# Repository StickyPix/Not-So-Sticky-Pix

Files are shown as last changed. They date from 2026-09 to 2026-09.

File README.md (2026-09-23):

# StickyPix

StickyPix is a small, rechargeable e-paper picture frame that lets you send
images from a phone or desktop app over Bluetooth Low Energy. The same product
family supports a four-gray black-and-white display and a six-color display.

## Image gallery

<table>
  <tr>
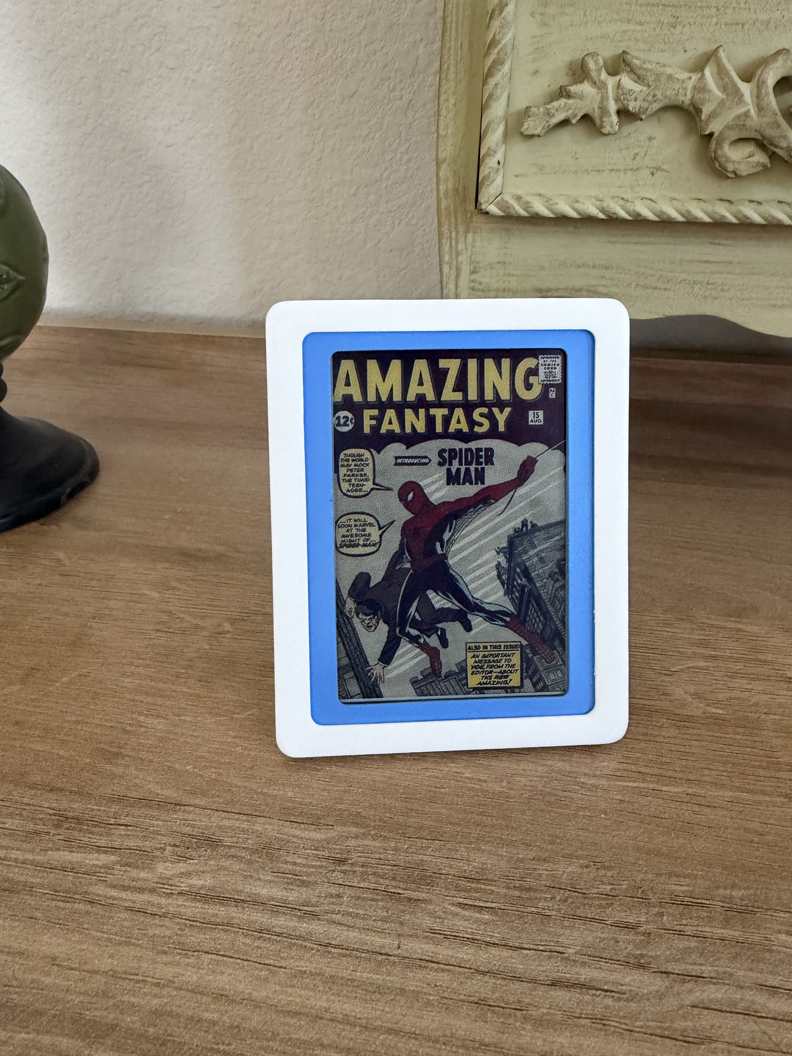
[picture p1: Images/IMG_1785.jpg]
StickyPix prototype photo 1
    <td></td>
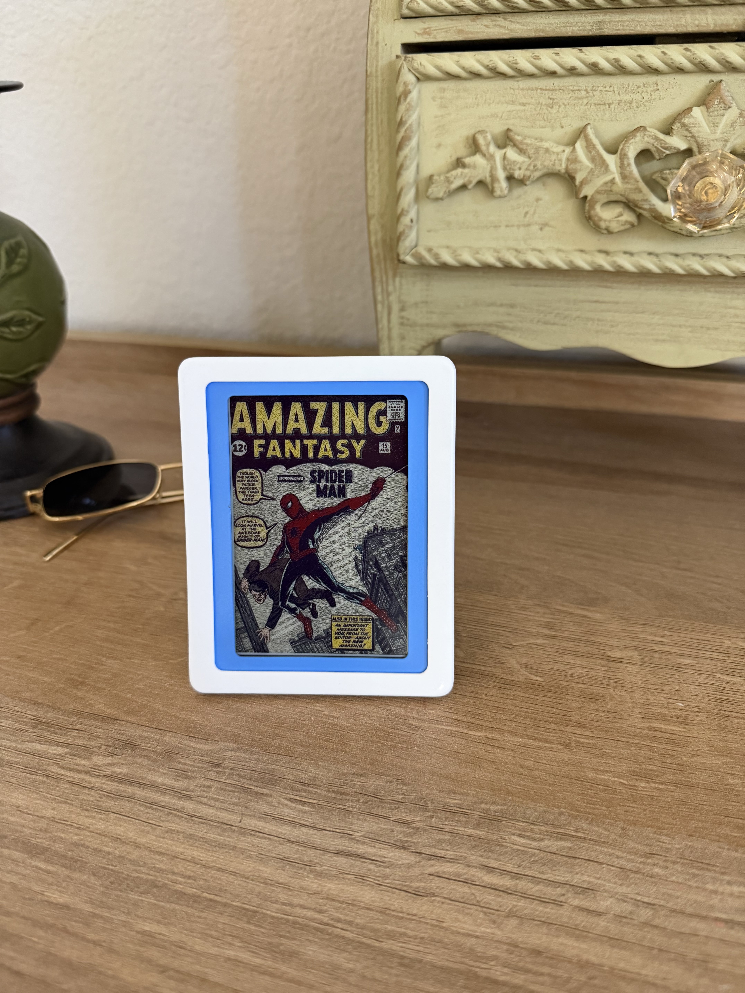
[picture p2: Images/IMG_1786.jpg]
StickyPix prototype photo 2
    <td></td>
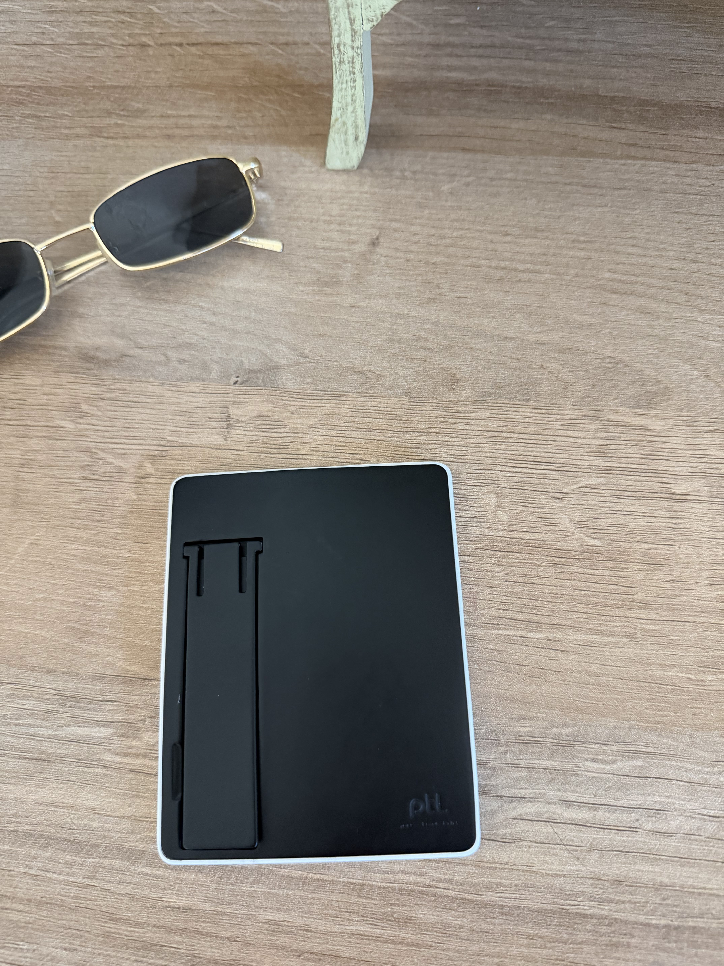
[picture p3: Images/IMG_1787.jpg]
StickyPix prototype photo 3
    <td></td>
  </tr>
  <tr>
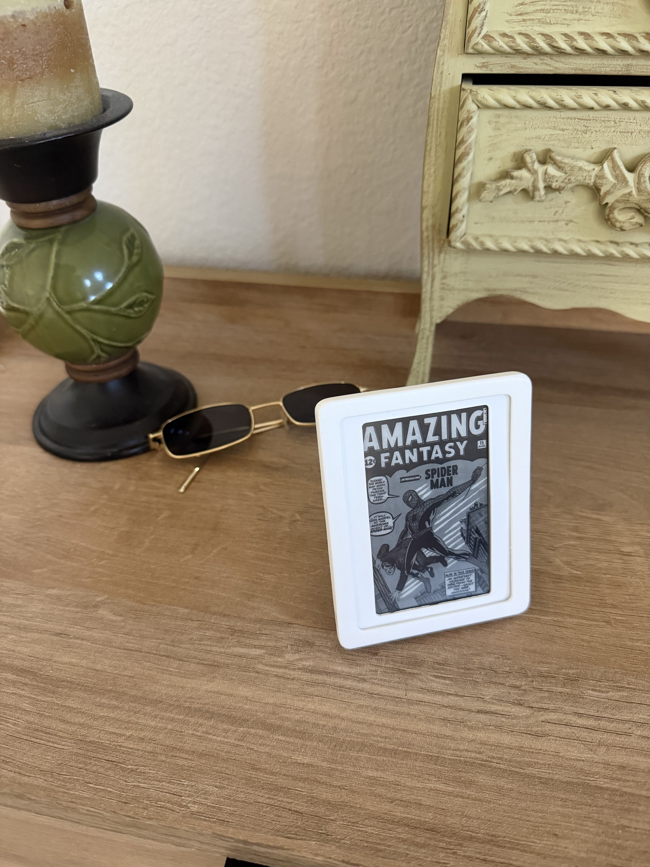
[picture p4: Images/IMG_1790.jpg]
StickyPix prototype photo 4
    <td></td>
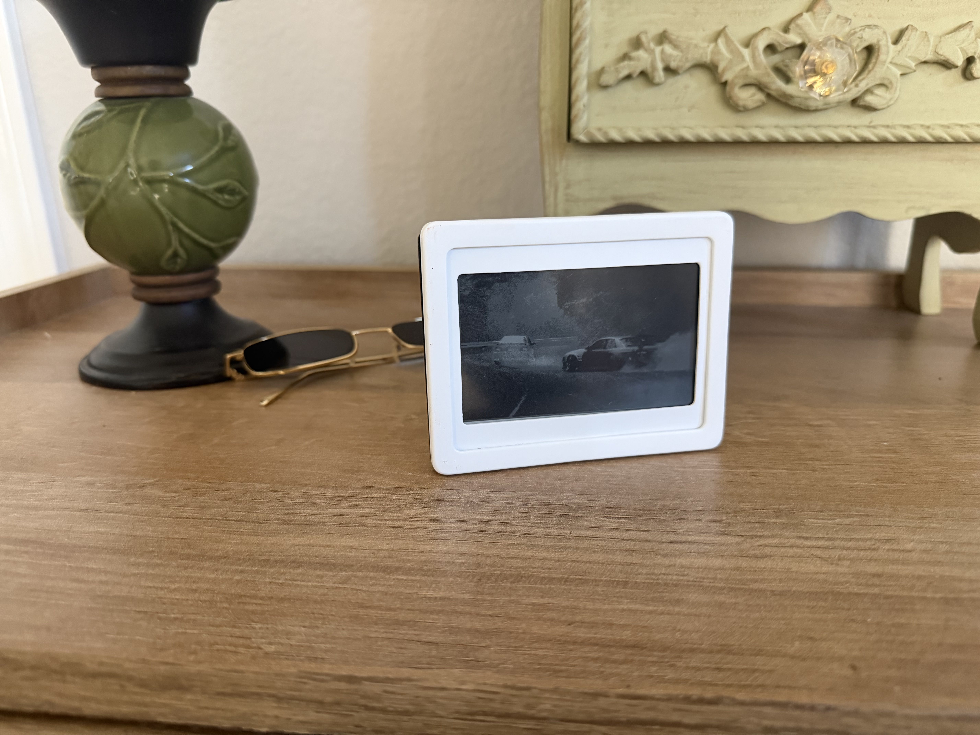
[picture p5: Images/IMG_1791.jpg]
StickyPix prototype photo 5
    <td></td>
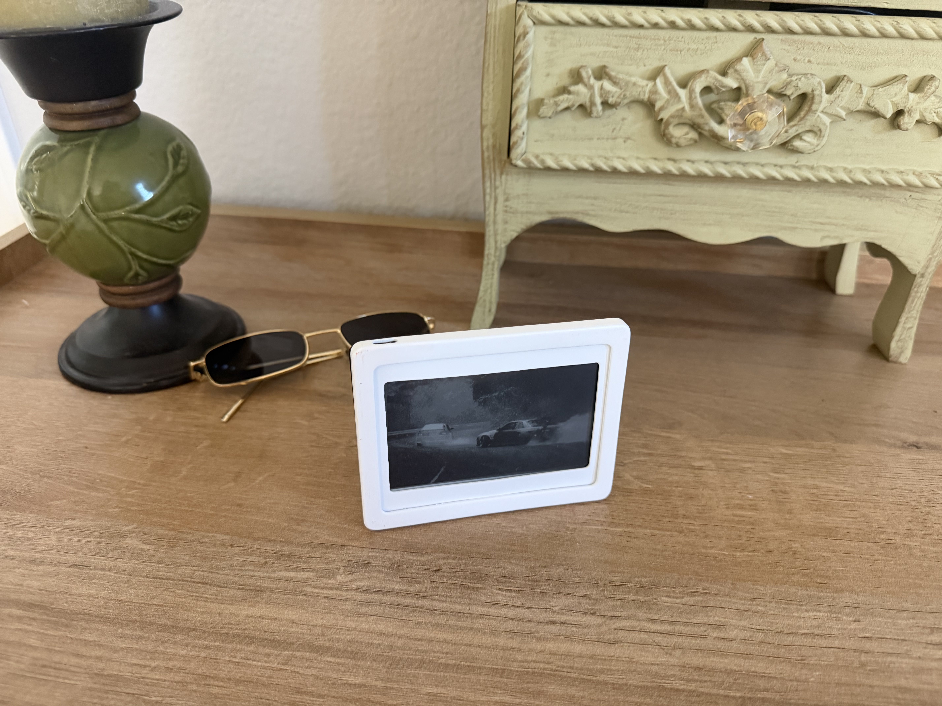
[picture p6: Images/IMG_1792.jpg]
StickyPix prototype photo 6
    <td></td>
  </tr>
  <tr>
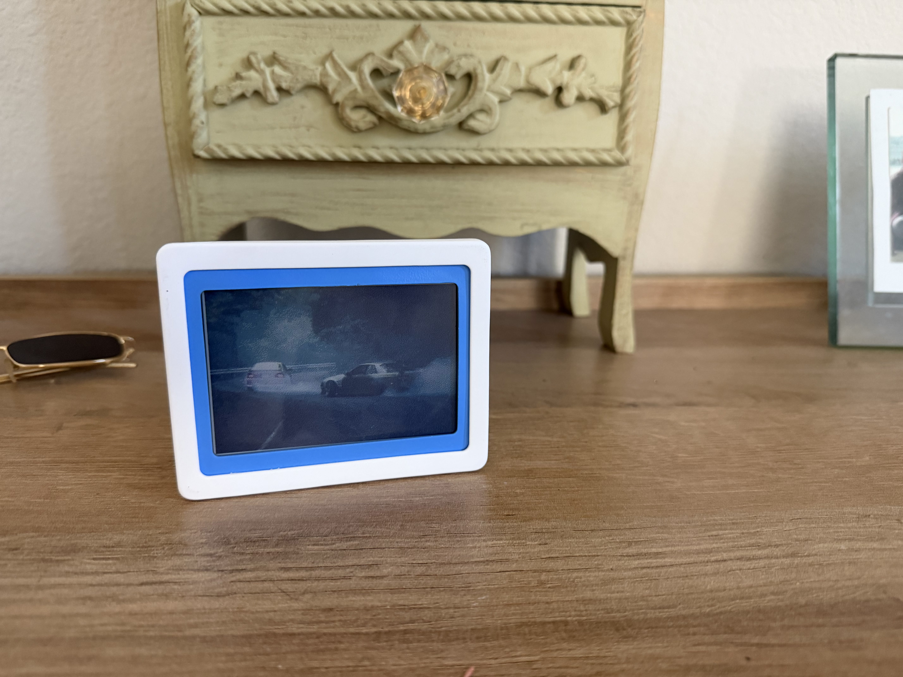
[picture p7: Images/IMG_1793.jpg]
StickyPix prototype photo 7
    <td></td>
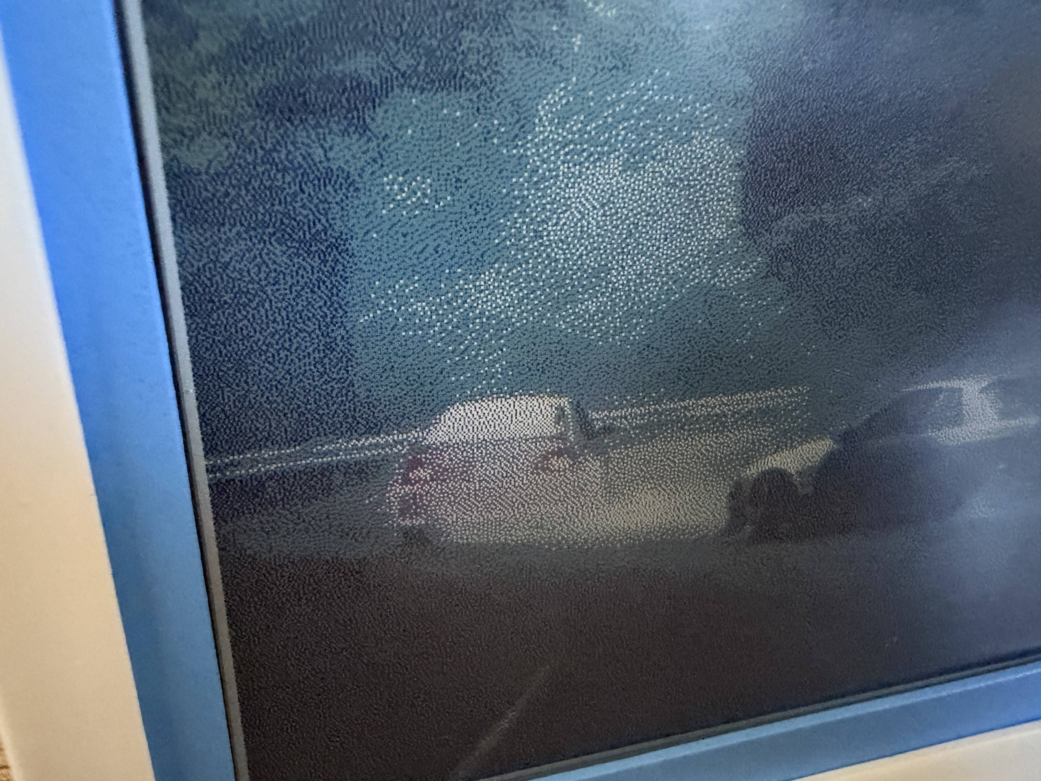
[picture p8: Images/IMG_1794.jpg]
StickyPix prototype photo 8
    <td></td>
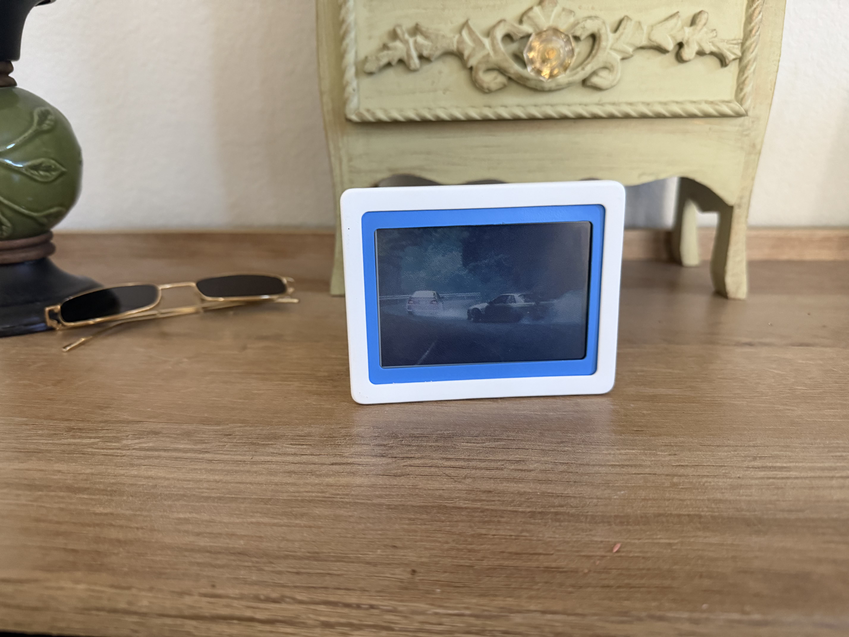
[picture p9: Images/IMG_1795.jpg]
StickyPix prototype photo 9
    <td></td>
  </tr>
</table>

## What is in this repository?

StickyPix is developed as a complete hardware and software product:

| Area | Contents |
| --- | --- |
| App | Flutter image editor, dithering previews, device management, and BLE image transfer |
| Firmware | Zephyr-based firmware for four-gray and six-color display variants |
| Hardware | KiCad schematics, PCBs, fabrication outputs, and bills of materials |
| Enclosure | Blender source files and printable STL parts for the bezel, rear shell, inner enclosure, and kickstand |
| Images | Prototype photos and product renders |

## How it works

1. Choose an image in the Flutter app.
2. Crop, rotate, and adjust the image for the selected device.
3. The app converts the image to the display's limited palette using dithering.
4. The processed framebuffer is sent to the device over BLE.
5. The device refreshes the e-paper panel and returns transfer progress and battery information.

The image pipeline currently supports:

- Four-gray output for the black-and-white display variant.
- Six-color output for black, white, yellow, red, blue, and green.
- Portrait and landscape editing for the six-color device.
- Packed framebuffer transfer sized for the target panel.

## Display variants

- [Six-color display / Spectra 6 panel](https://www.ebay.com/itm/267508191177?var=567305393025)
- [Black-and-white display panel](https://www.good-display.com/product/613.html)

The linked vendor pages are the reference parts for the current hardware
designs. Check the vendor documentation for the latest availability and
electrical specifications before ordering.

## JLCPCB fabrication settings

For the current PCB designs, I use the following JLCPCB configuration as the
fabrication reference:

| Setting | Value |
| --- | --- |
| Design | 1 |
| Delivery format | Single PCB |
| PCB thickness | 1.0 mm |
| PCB color | Green |
| Silkscreen | White |
| Material | FR4 TG135 |
| Surface finish | HASL (with lead) |
| Outer copper | 1 oz |
| Inner copper | 0.5 oz |
| Specify layer sequence | No |
| Specify stackup | Yes |
| Layer stackup | JLC04101H-3313 |

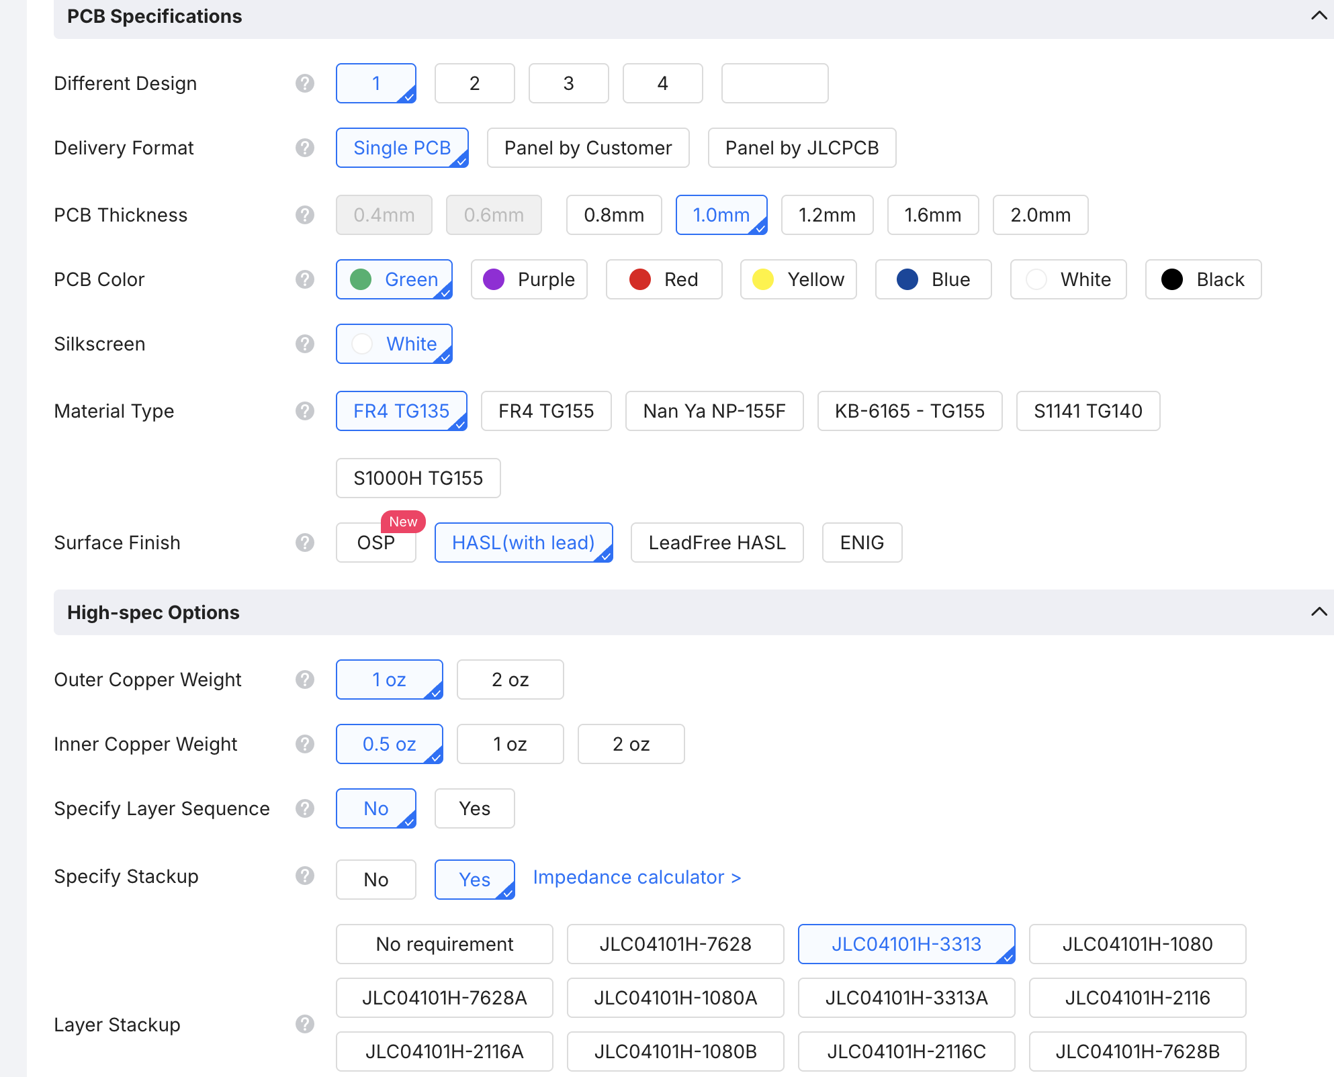
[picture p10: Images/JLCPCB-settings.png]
JLCPCB PCB specifications


Treat this as the current ordering reference, not a guarantee that every board
revision uses the same stackup. Recheck the board layer count, dimensions, and
JLCPCB options before placing an order.

## Enclosure

The enclosure is split into a front bezel, rear shell, inner cardstock/support
piece, and kickstand. The repository includes both the editable Blender model
and exported STL files.

<table>
  <tr>
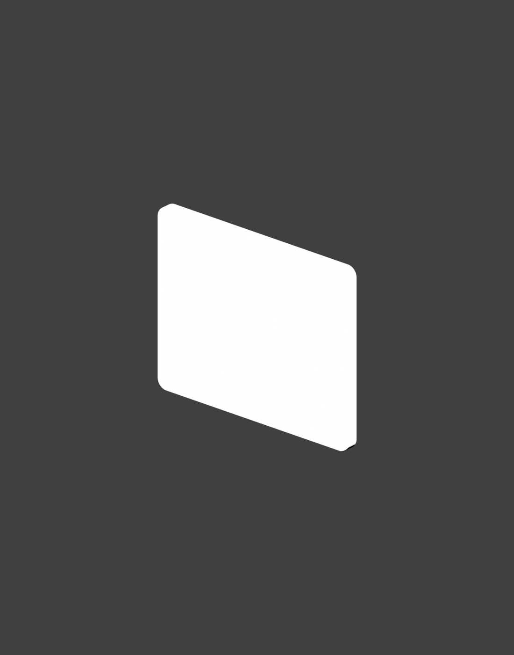
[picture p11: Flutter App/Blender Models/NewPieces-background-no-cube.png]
StickyPix enclosure render
    <td></td>
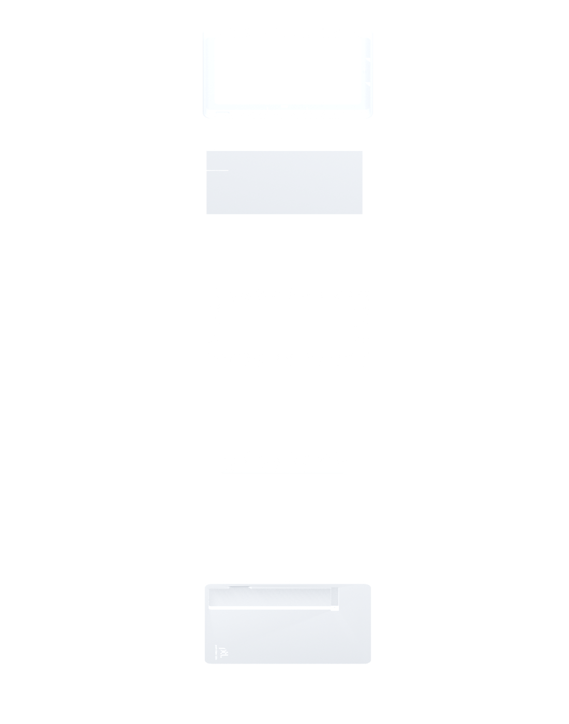
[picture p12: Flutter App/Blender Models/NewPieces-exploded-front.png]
StickyPix exploded enclosure render
    <td></td>
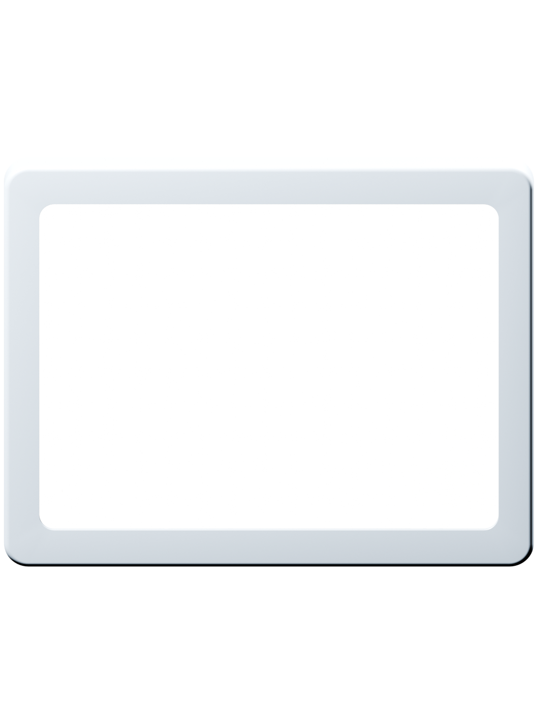
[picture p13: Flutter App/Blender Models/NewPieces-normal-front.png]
StickyPix enclosure front render
    <td></td>
  </tr>
</table>

## Repository layout

```text
Images/                         Prototype photos
3D Model/                       Printable enclosure STL files
Hardware/24p_bw_3p5/            Black-and-white KiCad design
Hardware/50p_spectra6_4/        Six-color KiCad design
Firmware/4GrayFinal/             Four-gray Zephyr firmware
Firmware/6ColorFinal/            Six-color Zephyr firmware
Flutter App/frontend/sticky_pix/ Flutter application
Manufacturing/                  Manufacturing files and BOM
```

## Project status

StickyPix is an active hardware prototype. The app, firmware, PCB designs, and
enclosure are included for development and iteration; dimensions, pinouts,
image timings, and manufacturing outputs may change.

## Development notes

The Flutter application is in `Flutter App/frontend/sticky_pix`. The firmware
projects use Zephyr and are kept separate so the four-gray and six-color panel
drivers can evolve independently. Build-tool-generated files and local SDK
paths should remain uncommitted.

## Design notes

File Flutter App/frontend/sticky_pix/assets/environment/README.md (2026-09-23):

# Studio image-based lighting

`default_env_ibl.ktx` is the Filament-compatible neutral environment bundled
with Thermion's own examples and tests:

https://github.com/nmfisher/thermion/blob/main/examples/assets/default_env_ibl.ktx

Only the indirect-light data is loaded. The environment is not displayed as a
skybox, so the Flutter background remains unchanged.

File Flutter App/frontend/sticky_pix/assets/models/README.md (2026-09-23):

# Product model contract

The viewer loads `device.glb` once and addresses model parts by glTF node name.
Keep these names stable in Blender:

- `4" Eink Display` — the complete display module in Blender. The preparation
  tool renames it `DisplayPlane` for reliable Thermion lookup and splits its
  recessed 84.6 × 56.4 mm active face into display primitive `2`.
- `Cube` — an export-only helper whose mesh is stripped from the packaged GLB.
  Thermion imports renderable nodes outside the active glTF scene, so scene
  exclusion alone is insufficient.
- `FrontShell (1.5Fillet) with clips (1)` — front bezel.
- `RearShell with Clips long` — rear enclosure.
- `Kickstand 1.5 (1) (1) (1)` — kickstand pivot object.
- `Cardstock 4` — inner enclosure.

The packaged model is generated from `Blender Models/NewPieces.glb` with
`tool/prepare_device_glb.dart`. It creates the dedicated `Display` primitive,
keeps the five named product pieces, excludes the unrelated `Cube`, applies the
safe mobile plastic material, and locks the product in portrait orientation.

Keep the display UV aspect ratio at 3:2 and orient UV0 so the upper-left of the
image appears at the upper-left of the physical display. Apply object scale and
rotation before export. Put the kickstand origin at its physical hinge and
export an animation named `KickstandOpen` when that animation is ready.

Recommended Blender materials:

- Front shell, cardstock, and kickstand PC/ABS: `#F5F5F5`.
- Rear shell PC/ABS: baby blue `#89CFF0`.
- All PC/ABS: metallic `0`, roughness `0.12` for a high-gloss finish.
  Thermion 0.4.1's default
  mobile ubershader cannot safely load the glTF clearcoat/IOR combination, so
  the glossy injection-molded finish is represented by low roughness instead.
- The export-only `Cube` is excluded because it is not one of the five named
  NewPieces product components.
- Display: matte black placeholder, with UV0 retained in the GLB.

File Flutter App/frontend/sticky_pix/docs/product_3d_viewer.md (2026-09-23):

# Reusable 3D product viewer

`Product3dViewer` is the Flutter presentation layer. It owns one Thermion
viewer, one loaded glTF asset, the camera input delegate, and GPU resources.
`ProductViewerController` is the application-facing API. The image processor
never talks directly to Filament.

## Runtime flow

1. The bundled 1.5 MB GLB is loaded once and normalized to a unit cube.
2. Named glTF entities receive independent Filament PBR material instances.
3. Primitive `2` of runtime entity `DisplayPlane` (the Blender node named
   `4" Eink Display`) receives an unlit texture material using UV0. The display
   module body and connector retain their own materials.
4. Processed PNG bytes are decoded and uploaded as a GPU texture.
5. The new texture replaces the old texture on the material; the model and UV
   mapping remain loaded and unchanged.
6. Edit and Save animate the existing camera between configurable poses.

## Public control surface

```dart
final controller = ProductViewerController();

Product3dViewer(controller: controller);

await controller.setDisplayTexture(processedPng);
await controller.focusDisplay();
await controller.showOverview();
await controller.setPartColor(ProductPart.kickstand, const Color(0xFF222222));
```

Each device model supplies a `ProductModelConfig`, so new hardware variants do
not require changes to rendering code. Put their node names, asset path, camera
poses, and optional IBL/skybox paths in a new config.

## Performance budget

- The render loop is capped at 60 FPS.
- The GLB is loaded once; image changes do not reload it.
- Display textures use mipmaps to avoid shimmer when the device rotates.
- GPU textures and custom material instances are explicitly released.
- The viewport is isolated behind a `RepaintBoundary`.
- Keep mobile GLBs below roughly 100k triangles, use one UV set for the
  display, prefer 1K–2K textures, and use KTX2/Basis textures for larger
  production assets.

## Blender/export contract

See `assets/models/README.md`. In particular, keep the part node names stable,
keep the `4" Eink Display` active surface dimensions unchanged, and position
the kickstand origin at its hinge. Export a `KickstandOpen` glTF animation
before adding the controller action for it.

For a more reflective studio look, add mobile-sized Filament IBL and skybox KTX
assets and set `iblPath`/`skyboxPath` on the model config. Direct three-point
lighting is the current fallback.

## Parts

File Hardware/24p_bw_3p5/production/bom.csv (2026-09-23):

Designator | Footprint | Quantity | Value | LCSC Part #
AE2 | 2.4GHz_Left_PC_ABS | 1 | Antenna_Shield
C1 | 0201 | 1 | 1.5pF
C10, C12, C14, C15, C44, C5, C7 | 0603 | 7 | 4.7uF
C16, C18 | 0402 | 2 | 1uF
C17 | 0201 | 1 | 3.9pF
C19, C28 | 0201 | 2 | 2.2uF
C2 | 0201 | 1 | 2pF
C20, C21, C22, C25 | 0201 | 4 | 100nF
C23 | 0201 | 1 | 2.2nF
C24 | 0402 | 1 | 0.1uF
C26, C29, C30 | 0402 | 3 | 10uF
C27 | 0201 | 1 | 10nF
C3, C6, C9 | 0603 | 3 | 1uF
C8 | 0201 | 1 | 0.3pF
D1, D2, D3 | D_SOD-323 | 3 | 1N5819WS
FB1 | 0201 | 1 | FerriteBead
J1 | HRS_FH34SRJ-24S-0.5SH_50_ | 1 | FH34SRJ-24S-0.5SH_50_
J2 | USB_C_SHOU_HAN_6P | 1 | USB_C_Receptacle_PowerOnly_6P
J3 | BATTERY_HC-1.2-2PWT | 1 | BATTERY
J4 | PinHeader_1x04_P2.54mm_Vertical | 1 | Conn_01x04_Pin
J5, J6 | PinHeader_1x03_P2.54mm_Vertical | 2 | Conn_01x03_Pin
L1 | 0201 | 1 | 2.7nH
L2, L3 | 0201 | 2 | 3.5nH
L4 | L_Cenker_CKCS3012 | 1 | 47uH
L5 | 0603 | 1 | 4.7uH
Q1 | SOT-323_SC-70 | 1 | Si1308EDL
R1 | 0402 | 1 | 2.2
R10, R7 | 0402 | 2 | 10k
R2, R4 | 0402 | 2 | 5.1k
R3 | 0402 | 1 | 1M
R5 | 0201 | 1 | 1k
R6 | 0402 | 1 | 5.4k
R8 | 0402 | 1 | 2k
R9 | 0402 | 1 | 100
U1 | DFN1006-2 | 1 | ESD5451N
U2 | IC_BQ24045DSQR | 1 | BQ24040DSQR
U3 | QFN40P600X600X90-49N | 1 | NRF54L15-QFAA-R
U4 | UDFN-4-1EP_1x1mm_P0.65mm_EP0.48x0.48mm | 1 | FH8614G1
U6 | SOT-23-3 | 1 | GR6206P332MR-G
Y2 | Crystal_SMD_2016-4Pin_2.0x1.6mm | 1 | Crystal_GND24

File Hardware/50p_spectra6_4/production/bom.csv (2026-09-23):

Designator | Footprint | Quantity | Value | LCSC Part #
AE1 | 2.4GHz_Left_Soldermask | 1 | Antenna_Shield
C1 | 0201 | 1 | 1.5pF
C10, C11, C37, C38, C39, C41, C5, C6, C7, C9 | 0603 | 10 | 10uF
C12 | 0402 | 1 | 470nF
C13 | 0402 | 1 | 100nF
C14, C31 | 0402 | 2 | 2.2uF
C15, C16, C18, C32, C33, C34, C35 | 0402 | 7 | 1uF
C17 | 0201 | 1 | 3.9pF
C19, C28 | 0201 | 2 | 2.2uF
C2 | 0201 | 1 | 2pF
C20, C21, C22, C25 | 0201 | 4 | 100nF
C23 | 0201 | 1 | 2.2nF
C24 | 0402 | 1 | 0.1uF
C26, C29, C30 | 0402 | 3 | 10uF
C27 | 0201 | 1 | 10nF
C3, C36, C40 | 0402 | 3 | 4.7uF
C4 | 0402 | 1 | 0.47uF
C8 | 0201 | 1 | 0.3pF
D1, D2, D3, D4 | D_SOD-123 | 4 | MBR0530
FB1 | 0201 | 1 | FerriteBead
J1, J5 | PinHeader_1x03_P2.54mm_Vertical | 2 | Conn_01x03_Pin
J2 | USB_C_SHOU_HAN_6P | 1 | USB_C_Receptacle_PowerOnly_6P
J3 | BATTERY_HC-1.2-2PWT | 1 | BATTERY
J4 | PinHeader_1x04_P2.54mm_Vertical | 1 | Conn_01x04_Pin
J6 | PinHeader_1x02_P2.54mm_Vertical | 1 | Conn_01x02_Pin
J7 | HRS_FH34SRJ-50S-0.5SH_50_ | 1 | FH34SRJ-50S-0.5SH_50_
L1 | 0201 | 1 | 2.7nH
L2, L3 | 0201 | 2 | 3.5nH
L4, L6 | L_Changjiang_FNR4012S | 2 | 10uH
L5 | 0603 | 1 | 4.7uH
Q1 | SOT95P237X111-3N | 1 | BSS138LT1G
Q2 | SOT-23 | 1 | SI2301CDS-T1-GE3
R1, R15 | 0402 | 2 | 1M
R10, R11, R2, R4 | 0402 | 4 | 5.1k
R12, R17, R18, R7 | 0402 | 4 | 10k
R13 | 0402 | 1 | 0.01
R14 | 0402 | 1 | 0
R16, R3 | 0402 | 2 | 0.2
R5 | 0201 | 1 | 1k
R6 | 0402 | 1 | 5.4k
R8 | 0402 | 1 | 2k
R9 | 0402 | 1 | 100
U1 | DFN1006-2 | 1 | ESD5451N
U2 | IC_BQ24045DSQR | 1 | BQ24040DSQR
U3 | QFN40P600X600X90-49N | 1 | NRF54L15-QFAA-R
U4 | UDFN-4-1EP_1x1mm_P0.65mm_EP0.48x0.48mm | 1 | FH8614G1
U5 | BGA9C50P3X3_158X162X62 | 1 | BQ27220YZFR
U6 | SOT-23-3 | 1 | GR6206P332MR-G
U7 | ZD25WQ80CEIGR | 1 | ZD25WQ80C
Y2 | Crystal_SMD_2016-4Pin_2.0x1.6mm | 1 | Crystal_GND24

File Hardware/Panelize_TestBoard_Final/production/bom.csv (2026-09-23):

Designator | Footprint | Quantity | Value | LCSC Part #
AE1 | 2.4GHz_Left_Soldermask | 1 | Antenna_Shield
AE2 | 2.4GHz_Left_PC_ABS | 1 | Antenna_Shield
C1_2, C1 | 0201 | 2 | 1.5pF
C10_2, C12_2, C14_2, C15_2, C44, C5_2, C7_2 | 0603 | 7 | 4.7uF
C10, C11, C37, C38, C39, C41, C5, C6, C7, C9 | 0603 | 10 | 10uF
C12 | 0402 | 1 | 470nF
C13 | 0402 | 1 | 100nF
C14, C31 | 0402 | 2 | 2.2uF
C15, C16_2, C16, C18_2, C18, C32, C33, C34, C35 | 0402 | 9 | 1uF
C17_2, C17 | 0201 | 2 | 3.9pF
C19_2, C19, C28_2, C28 | 0201 | 4 | 2.2uF
C2_2, C2 | 0201 | 2 | 2pF
C20_2, C20, C21_2, C21, C22_2, C22, C25_2, C25 | 0201 | 8 | 100nF
C23_2, C23 | 0201 | 2 | 2.2nF
C24_2, C24 | 0402 | 2 | 0.1uF
C26_2, C26, C29_2, C29, C30_2, C30 | 0402 | 6 | 10uF
C27_2, C27 | 0201 | 2 | 10nF
C3_2, C6_2, C9_2 | 0603 | 3 | 1uF
C3, C36, C40 | 0402 | 3 | 4.7uF
C4 | 0402 | 1 | 0.47uF
C8_2, C8 | 0201 | 2 | 0.3pF
D1_2, D2_2, D3_2 | D_SOD-323 | 3 | 1N5819WS
D1, D2, D3, D4 | D_SOD-123 | 4 | MBR0530
FB1_2, FB1 | 0201 | 2 | FerriteBead
J1_2 | HRS_FH34SRJ-24S-0.5SH_50_ | 1 | FH34SRJ-24S-0.5SH_50_
J1, J5_2, J5, J6_2 | PinHeader_1x03_P2.54mm_Vertical | 4 | Conn_01x03_Pin
J2_2, J2 | USB_C_SHOU_HAN_6P | 2 | USB_C_Receptacle_PowerOnly_6P
J3_2, J3 | BATTERY_HC-1.2-2PWT | 2 | BATTERY
J4_2, J4 | PinHeader_1x04_P2.54mm_Vertical | 2 | Conn_01x04_Pin
J6 | PinHeader_1x02_P2.54mm_Vertical | 1 | Conn_01x02_Pin
J7 | HRS_FH34SRJ-50S-0.5SH_50_ | 1 | FH34SRJ-50S-0.5SH_50_
L1_2, L1 | 0201 | 2 | 2.7nH
L2_2, L2, L3_2, L3 | 0201 | 4 | 3.5nH
L4_2 | L_Cenker_CKCS3012 | 1 | 47uH
L4, L6 | L_Changjiang_FNR4012S | 2 | 10uH
L5_2, L5 | 0603 | 2 | 4.7uH
MOUSE-BITE-3MM-SLOT_3, MOUSE-BITE-3MM-SLOT_2, MOUSE-BITE-3MM-SLOT | mouse-bite-3mm-slot | 3 | VAL**
Q1_2 | SOT-323_SC-70 | 1 | Si1308EDL
Q1 | SOT95P237X111-3N | 1 | BSS138LT1G
Q2 | SOT-23 | 1 | SI2301CDS-T1-GE3
R1_2 | 0402 | 1 | 2.2
R1, R15, R3_2 | 0402 | 3 | 1M
R10_2, R12, R17, R18, R7_2, R7 | 0402 | 6 | 10k
R10, R11, R2_2, R2, R4_2, R4 | 0402 | 6 | 5.1k
R13 | 0402 | 1 | 0.01
R14 | 0402 | 1 | 0
R16, R3 | 0402 | 2 | 0.2
R5_2, R5 | 0201 | 2 | 1k
R6_2, R6 | 0402 | 2 | 5.4k
R8_2, R8 | 0402 | 2 | 2k
R9_2, R9 | 0402 | 2 | 100
U1_2, U1 | DFN1006-2 | 2 | ESD5451N
U2_2, U2 | IC_BQ24045DSQR | 2 | BQ24040DSQR
U3_2, U3 | QFN40P600X600X90-49N | 2 | NRF54L15-QFAA-R
U4_2, U4 | UDFN-4-1EP_1x1mm_P0.65mm_EP0.48x0.48mm | 2 | FH8614G1
U5 | BGA9C50P3X3_158X162X62 | 1 | BQ27220YZFR
U6_2, U6 | SOT-23-3 | 2 | GR6206P332MR-G
Y2_2, Y2 | Crystal_SMD_2016-4Pin_2.0x1.6mm | 2 | Crystal_GND24

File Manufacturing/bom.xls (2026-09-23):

Comment | Designator | Footprint | JLCPCB Part # | Qty | Ext.Price($)
NRF54L15-QFAA-R | U3_2,U3 | QFN40P600X600X90-49N | C42458750 | 4 | 0.00
2.2nF | C23_2,C23 | 0201 | C80433 | 20 | 0.03
1k | R5_2,R5 | 0201 | C100125 | 20 | 0.02
4.7uH | L5_2,L5 | 0603 | C1034 | 20 | 0.44
MBR0530 | D1,D2,D3,D4 | D_SOD-123 | C77336 | 12 | 0.44
10uF | C10,C11,C37,C38,C39,C41,C5,C6,C7,C9 | 0603 | C96446 | 28 | 1.48
10k | R10_2,R12,R17,R18,R7_2,R7 | 0402 | C25744 | 22 | 0.06
4.7uF | C3,C36,C40 | 0402 | C2858031 | 10 | 0.70
ESD5451N | U1_2,U1 | DFN1006-2 | C5261080 | 20 | 0.15
0.1uF | C13,C24_2,C24 | 0402 | C307331 | 20 | 0.15
4.7uF | C10_2,C12_2,C14_2,C15_2,C44,C5_2,C7_2 | 0603 | C69335 | 22 | 1.07
2.2uF | C19_2,C19,C28_2,C28 | 0201 | C318539 | 20 | 0.44
100nF | C20_2,C20,C21_2,C21,C22_2,C22,C25_2,C25 | 0201 | C76934 | 28 | 0.06
3.5nH | L2_2,L2,L3_2,L3 | 0201 | C3911055 | 12 | 0.78
1.5pF | C1_2,C1 | 0201 | C435397 | 20 | 0.72
1N5819WS | D1_2,D2_2,D3_2 | D_SOD-323 | C191023 | 20 | 0.22
2pF | C2_2,C2 | 0201 | C668326 | 20 | 0.50
2.2uF | C14,C31 | 0402 | C72203 | 8 | 0.38
5.1k | R10,R11,R2_2,R2,R4_2,R4 | 0402 | C25905 | 22 | 0.02
2k | R8_2,R8 | 0402 | C4109 | 20 | 0.02
1M | R1,R15,R3_2 | 0402 | C26083 | 20 | 0.02
GR6206P332MR-G | U6_2,U6 | SOT-23-3 | C19631737 | 10 | 0.14
FerriteBead | FB1_2,FB1 | 0201 | C83991 | 20 | 0.29
1uF | C3_2,C6_2,C9_2 | 0603 | C15849 | 20 | 0.59
BQ24040DSQR | U2_2,U2 | IC_BQ24045DSQR | C81080 | 5 | 1.89
10uH | L4,L6 | L_Changjiang_FNR4012S | C525662 | 6 | 0.79
0.01 | R13 | 0402 | C2089431 | 5 | 0.64
Si1308EDL | Q1_2 | SOT-323_SC-70 | C7603347 | 6 | 0.54
10nF | C27_2,C27 | 0201 | C285010 | 20 | 0.04
100 | R9_2,R9 | 0402 | C25076 | 20 | 0.02
FH34SRJ-24S-0.5SH_50_ | J1_2 | HRS_FH34SRJ-24S-0.5SH_50_ | C324726 | 2 | 0.57
0.3pF | C8_2,C8 | 0201 | C301897 | 20 | 0.02
FH8614G1 | U4_2,U4 | UDFN-4-1EP_1x1mm_P0.65mm_EP0.48x0.48mm | C2929074 | 6 | 0.17
5.4k | R6_2,R6 | 0402 | C5948099 | 20 | 0.68
FH34SRJ-50S-0.5SH_50_ | J7 | HRS_FH34SRJ-50S-0.5SH_50_ | C3169104 | 2 | 1.16
10uF | C26_2,C26,C29_2,C29,C30_2,C30 | 0402 | C15525 | 22 | 0.43
0.2 | R16,R3 | 0402 | C270629 | 20 | 0.12
1uF | C15,C16_2,C16,C18_2,C18,C32,C33,C34,C35 | 0402 | C52923 | 28 | 0.39
BQ27220YZFR | U5 | BGA9C50P3X3_158X162X62 | C528617 | 2 | 1.30
2.7nH | L1_2,L1 | 0201 | C7216765 | 8 | 0.28
BATTERY | J3_2,J3 | BATTERY_HC-1.2-2PWT | C2997425 | 6 | 0.89
3.9pF | C17_2,C17 | 0201 | C76926 | 20 | 0.04
0 | R14 | 0402 | C17168 | 20 | 0.02
0.47uF | C4,C12 | 0402 | C2443204 | 20 | 0.30
BSS138LT1G | Q1 | SOT95P237X111-3N | C82045 | 6 | 0.25
Crystal_GND24 | Y2_2,Y2 | Crystal_SMD_2016-4Pin_2.0x1.6mm | C718072 | 6 | 0.65
USB_C_Receptacle_PowerOnly_6P | J2_2,J2 | USB_C_SHOU_HAN_6P | C2858273 | 4 | 0.29
47uH | L4_2 | L_Cenker_CKCS3012 | C5289292 | 6 | 0.27
2.2 | R1_2 | 0402 | C325532 | 20 | 0.07
SI2301CDS-T1-GE3 | Q2 | SOT-23 | C10487 | 6 | 0.43

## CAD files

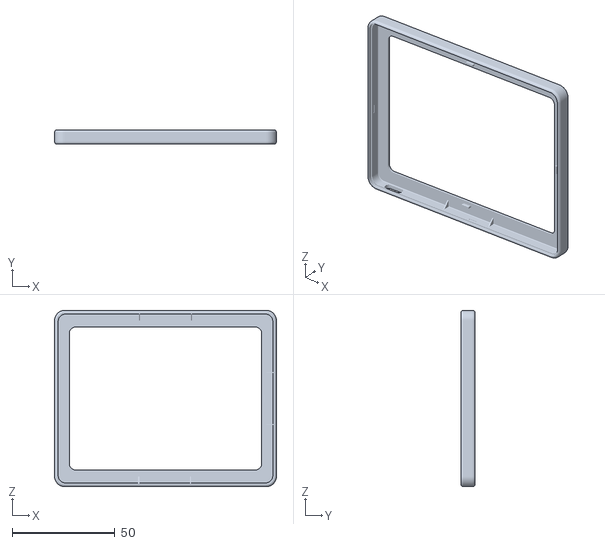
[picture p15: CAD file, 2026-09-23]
3D Model/FrontShell (1.5Fillet) with clips (1).stl
108.0 x 6.95 x 85.8

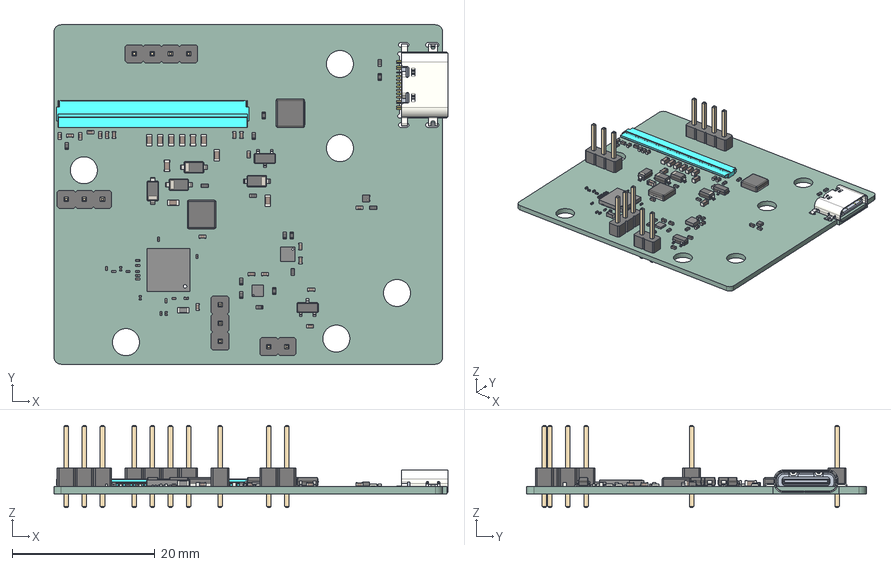
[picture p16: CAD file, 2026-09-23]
Hardware/50p_spectra6_4/50p_spectra6_4.step
55.2 x 47.6 x 11.5 mm
R_0402_1005Metric x 15
C_0201_0603Metric x 13
D_SOD_123 x 4
L_0603_1608Metric
C_0402_1005Metric x 19
C_0603_1608Metric x 10
L_Changjiang_FNR4012S x 2
NRF54L15-QFAA-R
DFN_4_1EP_1x1mm_P065mm_EP05x05mm
L_0201_0603Metric x 3
6_50_83D0001
PinHeader_1x03_P254mm_Vertical x 2
FH34SRJ-50S-0.5SH
DSQ10
PinHeader_1x02_P254mm_Vertical
SOT_23
R_0201_0603Metric
BQ27427YZFR
SOT-23-3
PinHeader_1x04_P254mm_Vertical
50p_spectra6_4_PCB_1
50p_spectra6_4_PCB_2

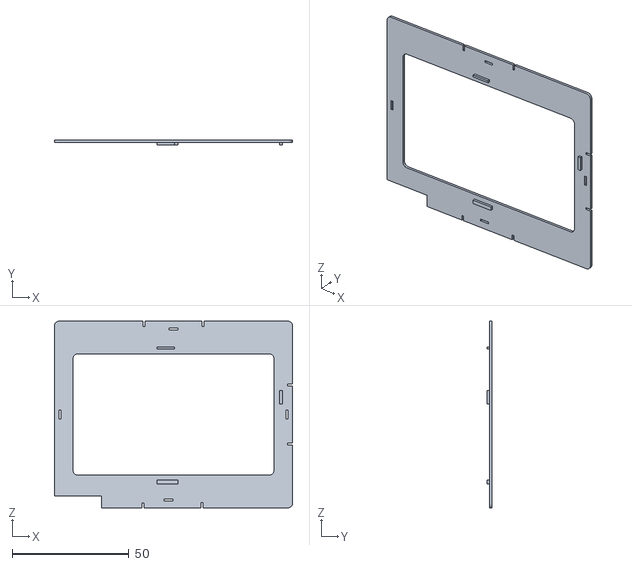
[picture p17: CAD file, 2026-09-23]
3D Model/Cardstock 3.97.stl
102.0 x 2.00 x 80.0

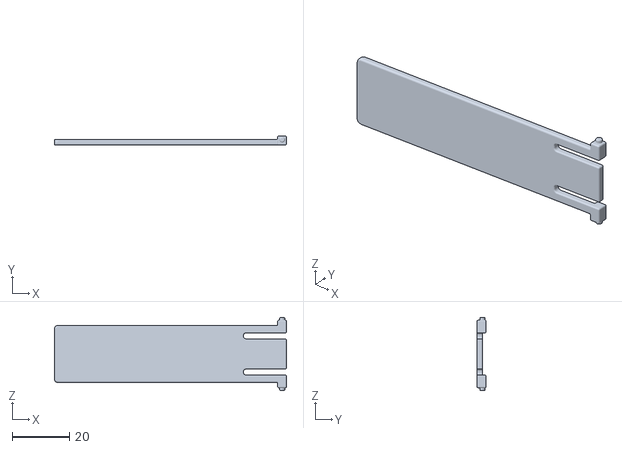
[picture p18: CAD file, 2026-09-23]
3D Model/Kickstand 1.5 newest.stl
81.0 x 3.20 x 25.6

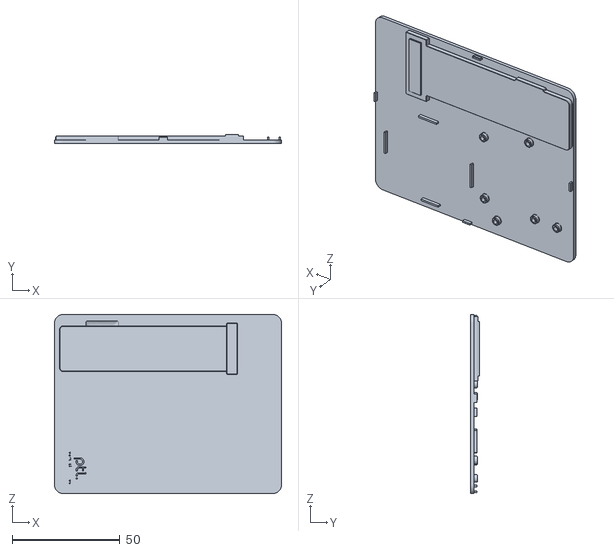
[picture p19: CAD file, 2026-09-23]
3D Model/RearShell with Clips long.stl
105.5 x 4.10 x 83.2

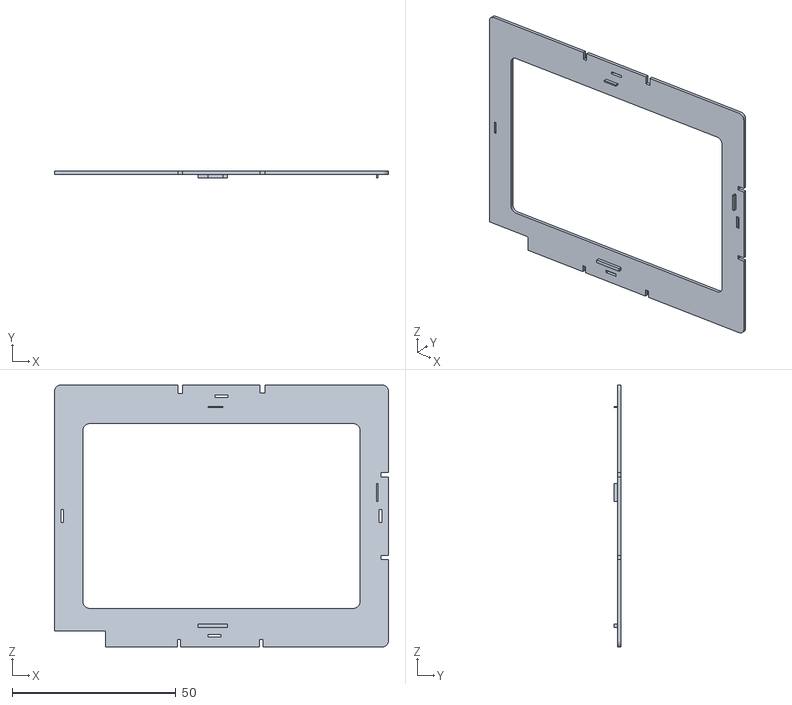
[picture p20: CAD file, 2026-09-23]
3D Model/Cardstock 4.stl
102.0 x 2.00 x 80.0

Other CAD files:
3D Model/Spectra6_4in.f3z
Flutter App/Blender Models/3DMODEL4IN.blend
Flutter App/Blender Models/NewPieces.blend

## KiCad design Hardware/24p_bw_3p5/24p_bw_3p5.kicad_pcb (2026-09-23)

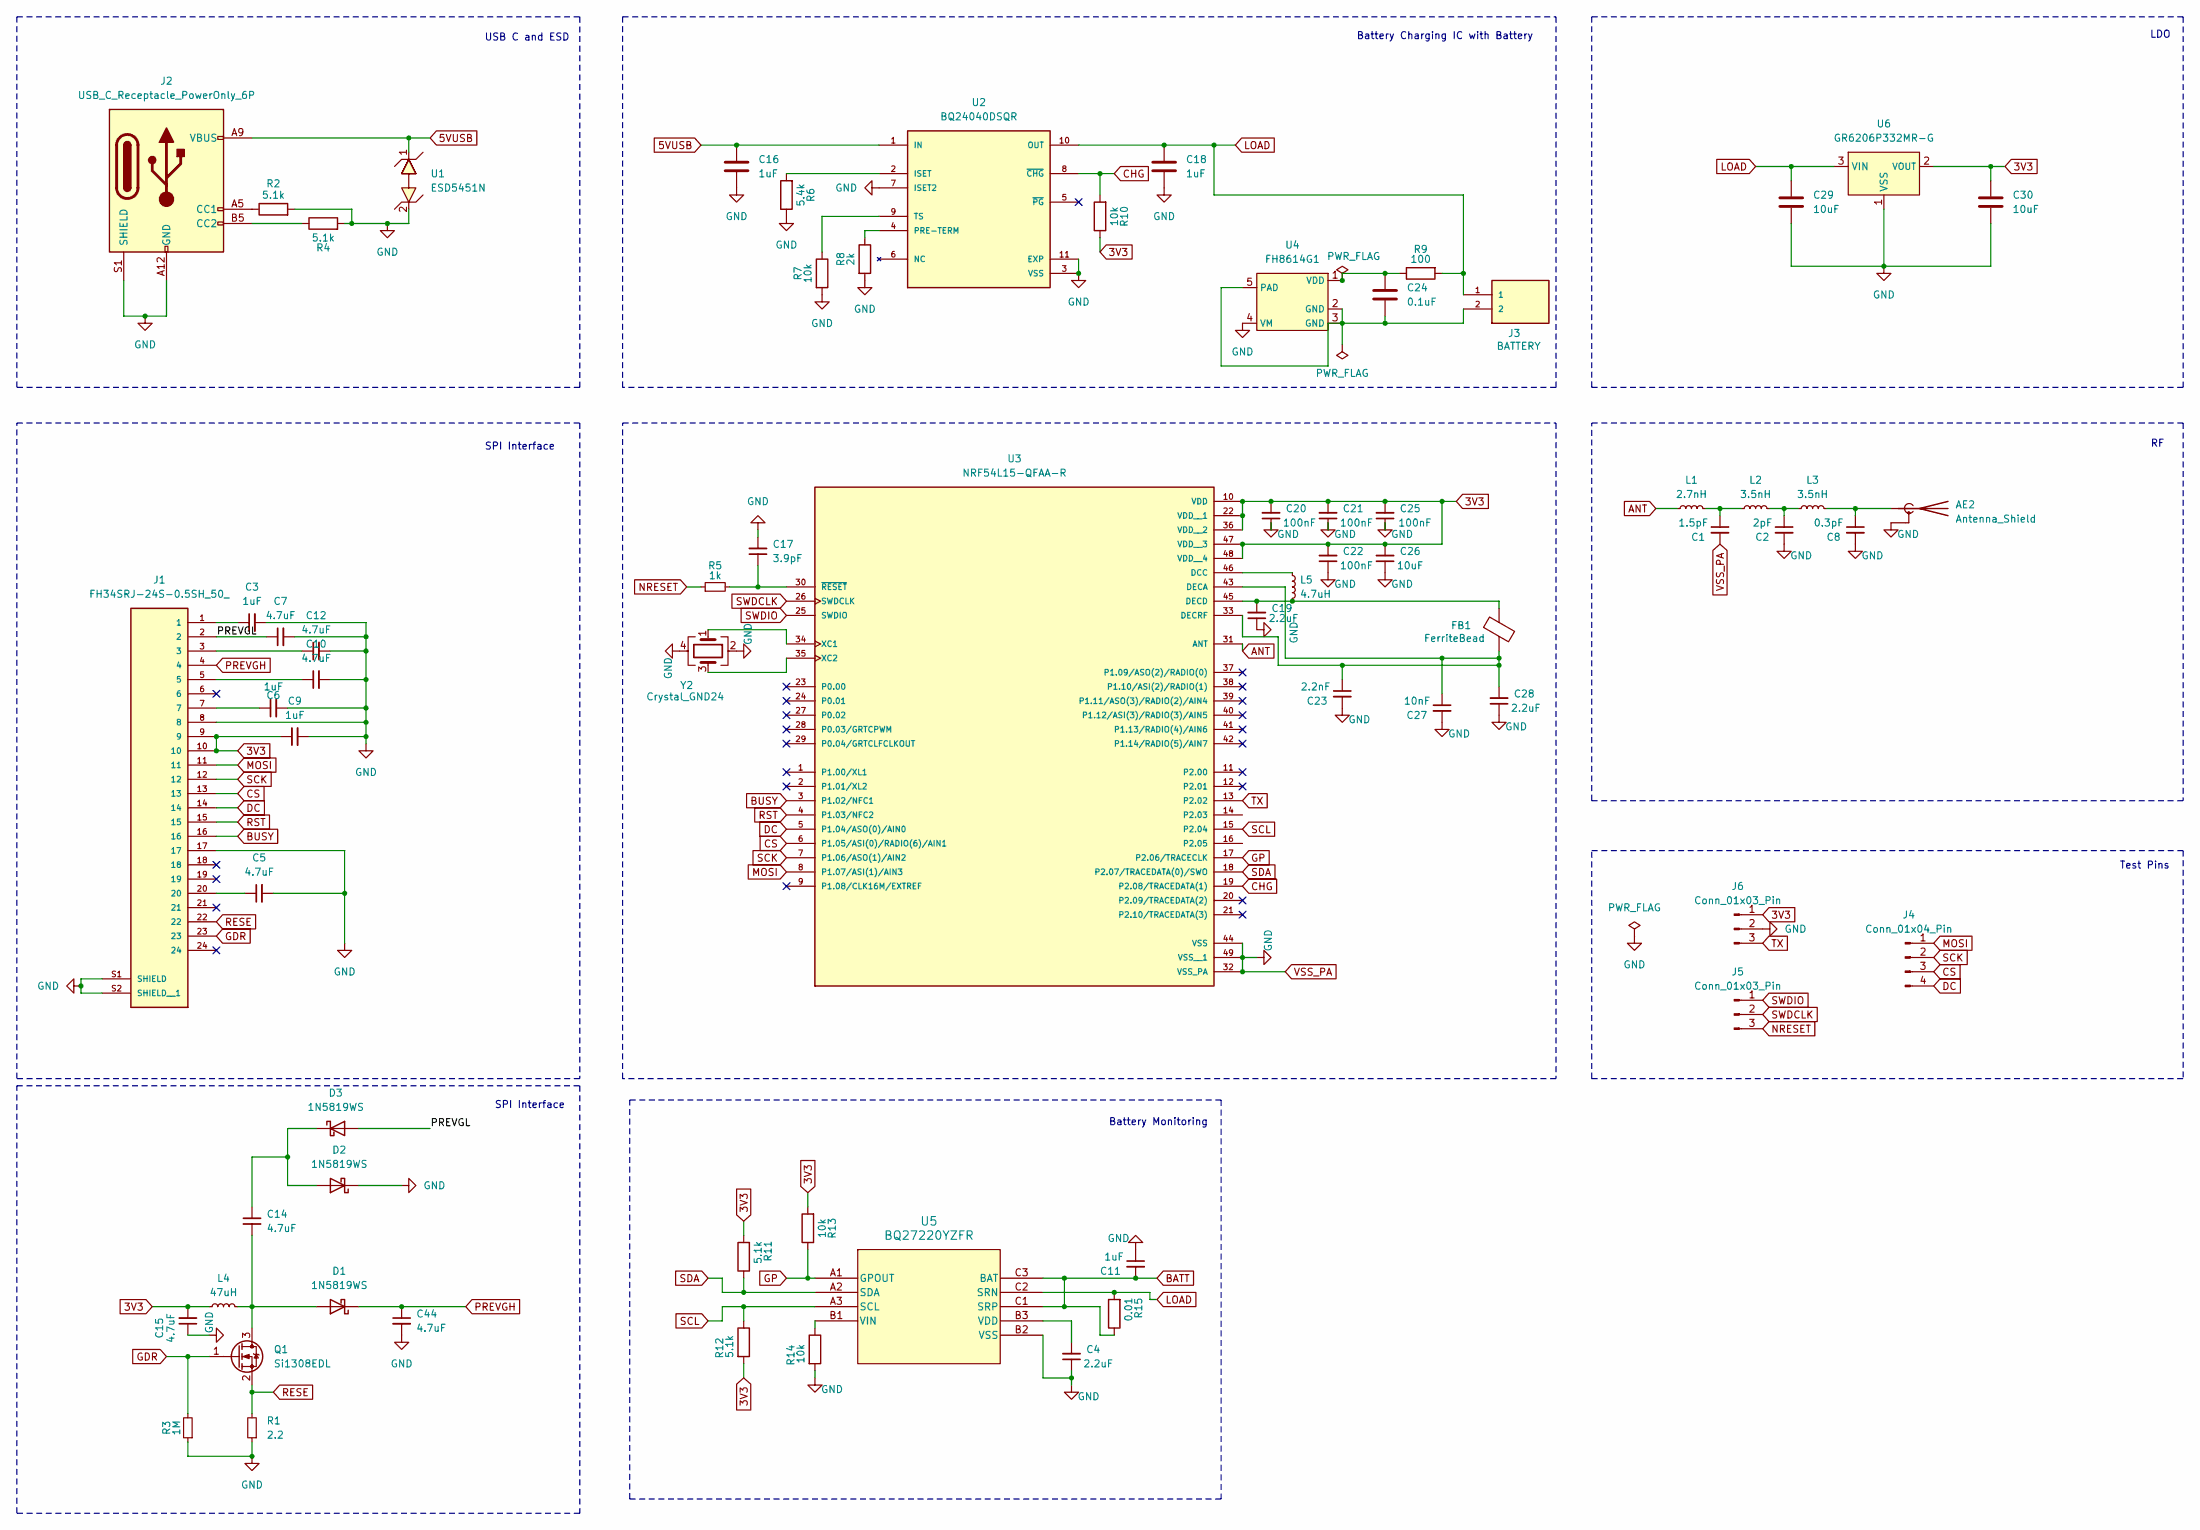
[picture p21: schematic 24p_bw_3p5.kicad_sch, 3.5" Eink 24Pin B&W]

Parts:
AE2: Antenna_Shield; 2.4GHz_Left_PC_ABS
C1: 1.5pF; RF_0201_0603Metric
C2: 2pF; RF_0201_0603Metric
C3, C6, C9: 1uF; C_0603_1608Metric
C4: 2.2uF; C_0402_1005Metric
C5, C7, C10, C12, C14, C15, C44: 4.7uF; C_0603_1608Metric
C8: 0.3pF; RF_0201_0603Metric
C11, C16, C18: 1uF; C_0402_1005Metric
C17: 3.9pF; C_0201_0603Metric
C19, C28: 2.2uF; C_0201_0603Metric
C20, C21, C22, C25: 100nF; C_0201_0603Metric
C23: 2.2nF; C_0201_0603Metric
C24: 0.1uF; C_0402_1005Metric
C26, C29, C30: 10uF; C_0402_1005Metric
C27: 10nF; C_0201_0603Metric
D1, D2, D3: 1N5819WS; D_SOD-323
FB1: FerriteBead; C_0201_0603Metric
J1: FH34SRJ-24S-0.5SH_50_; HRS_FH34SRJ-24S-0.5SH_50_
J2: USB_C_Receptacle_PowerOnly_6P; USB_C_SHOU_HAN_6P
J3: BATTERY; BATTERY_HC-1.2-2PWT
J4: Conn_01x04_Pin; PinHeader_1x04_P2.54mm_Vertical
J5, J6: Conn_01x03_Pin; PinHeader_1x03_P2.54mm_Vertical
L1: 2.7nH; RF_0201_0603Metric
L2, L3: 3.5nH; RF_0201_0603Metric
L4: 47uH; L_Cenker_CKCS3012
L5: 4.7uH; L_0603_1608Metric
Q1: Si1308EDL; SOT-323_SC-70
R1: 2.2; R_0402_1005Metric
R2, R4, R11, R12: 5.1k; R_0402_1005Metric
R3: 1M; R_0402_1005Metric
R5: 1k; R_0201_0603Metric
R6: 5.4k; R_0402_1005Metric
R7, R10, R13, R14: 10k; R_0402_1005Metric
R8: 2k; R_0402_1005Metric
R9: 100; R_0402_1005Metric
R15: 0.01; R_0402_1005Metric
U1: ESD5451N; DFN1006-2
U2: BQ24040DSQR; IC_BQ24045DSQR; PARTREV H
U3: NRF54L15-QFAA-R; QFN40P600X600X90-49N; PARTREV 0.8
U4: FH8614G1; UDFN-4-1EP_1x1mm_P0.65mm_EP0.48x0.48mm
U5: BQ27220YZFR; BGA9C50P3X3_158X162X62
U6: GR6206P332MR-G; SOT-23-3
Y2: Crystal_GND24; Crystal_SMD_2016-4Pin_2.0x1.6mm

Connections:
3V3: C9.1, C15.2, C20.2, C21.2, C22.2, C25.2, C26.2, C30.1, J1.9, J1.10, J6.1, L4.1, R10.1, R11.2, R12.2, R13.2, U3.10 (VDD), U3.22 (VDD__1), U3.36 (VDD__2), U3.47 (VDD__3), U3.48 (VDD__4), U6.2 (VOUT)
5VUSB: C16.1, J2.A9 (VBUS), J2.B9 (VBUS), U1.1, U2.1 (IN)
/PREVGL: C7.1, D3.2 (A), J1.2
ANT: L1.1, U3.31 (ANT)
BATT: C11.2, R15.1, U5.C1 (SRP), U5.C3 (BAT)
BUSY: J1.16, U3.3 (P1.02/NFC1)
CHG: R10.2, U2.8 (~CHG), U3.19 (P2.08/TRACEDATA(1))
CS: J1.13, J4.3, U3.6 (P1.05/ASI(0)/RADIO(6)/AIN1)
DC: J1.14, J4.4, U3.5 (P1.04/ASO(0)/AIN0)
GDR: J1.23, Q1.1 (G), R3.2
GP: R13.1, U3.17 (P2.06/TRACECLK), U5.A1 (GPOUT)
LOAD: C18.1, C29.1, J3.1, R9.2, R15.2, U2.10 (OUT), U5.C2 (SRN), U6.3 (VIN)
MOSI: J1.11, J4.1, U3.8 (P1.07/ASI(1)/AIN3)
NRESET: J5.3, R5.1
unnamed: AE2.1 (A), C8.1, L3.2
unnamed: C1.1, L1.2, L2.1
unnamed: C2.1, L2.2, L3.1
unnamed: C3.1, J1.1
unnamed: C5.1, J1.20
unnamed: C6.1, J1.7
unnamed: C10.1, J1.5
unnamed: C12.1, J1.3
unnamed: C14.2, D1.2 (A), L4.2, Q1.3 (D)
unnamed: C14.1, D2.2 (A), D3.1 (K)
unnamed: J2.A5 (CC1), R2.1
unnamed: J2.B5 (CC2), R4.1
unnamed: R6.2, U2.2 (ISET)
unnamed: R8.1, U2.4 (PRE-TERM)
unnamed: R7.1, U2.9 (TS)
unnamed: L5.1, U3.46 (DCC)
unnamed: C23.1, C27.1, C28.2, FB1.2, U3.33 (DECRF), U3.43 (DECA)
unnamed: C19.2, FB1.1, L5.2, U3.45 (DECD)
unnamed: U3.34 (XC1), Y2.1
unnamed: U3.35 (XC2), Y2.3
unnamed: C17.1, R5.2, U3.30 (~RESET)
unnamed: C24.2, J3.2, U4.2 (GND), U4.3 (GND), U4.5 (PAD)
unnamed: C24.1, R9.1, U4.1 (VDD)
unnamed: C4.2, U5.B3 (VDD)
unnamed: R14.1, U5.B1 (VIN)
PREVGH: C44.1, D1.1 (K), J1.4
RESE: J1.22, Q1.2 (S), R1.2
RST: J1.15, U3.4 (P1.03/NFC2)
SCK: J1.12, J4.2, U3.7 (P1.06/ASO(1)/AIN2)
SCL: R12.1, U3.15 (P2.04), U5.A3 (SCL)
SDA: R11.1, U3.18 (P2.07/TRACEDATA(0)/SWO), U5.A2 (SDA)
SWDCLK: J5.2, U3.26 (SWDCLK)
SWDIO: J5.1, U3.25 (SWDIO)
TX: J6.3, U3.13 (P2.02)
VSS_PA: AE2.2 (Shield), C1.2, C2.2, C3.2, C4.1, C5.2, C6.2, C7.2, C8.2, C9.2, C10.2, C11.1, C12.2, C15.1, C16.2, C17.2, C18.2, C19.1, C20.1, C21.1, C22.1, C23.2, C25.1, C26.1, C27.2, C28.1, C29.2, C30.2, C44.2, D2.1 (K), J1.8, J1.17, J1.S1 (SHIELD), J1.S2 (SHIELD__1), J2.A12 (GND), J2.B12 (GND), J2.S1 (SHIELD), J6.2, R1.1, R2.2, R3.1, R4.2, R6.1, R7.2, R8.2, R14.2, U1.2, U2.3 (VSS), U2.7 (ISET2), U2.11 (EXP), U3.32 (VSS_PA), U3.44 (VSS), U3.49 (VSS__1), U4.4 (VM), U5.B2 (VSS), U6.1 (VSS), Y2.2, Y2.4

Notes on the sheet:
Test Pins
Battery Monitoring
Battery Charging IC with Battery
SPI Interface
LDO
USB C and ESD

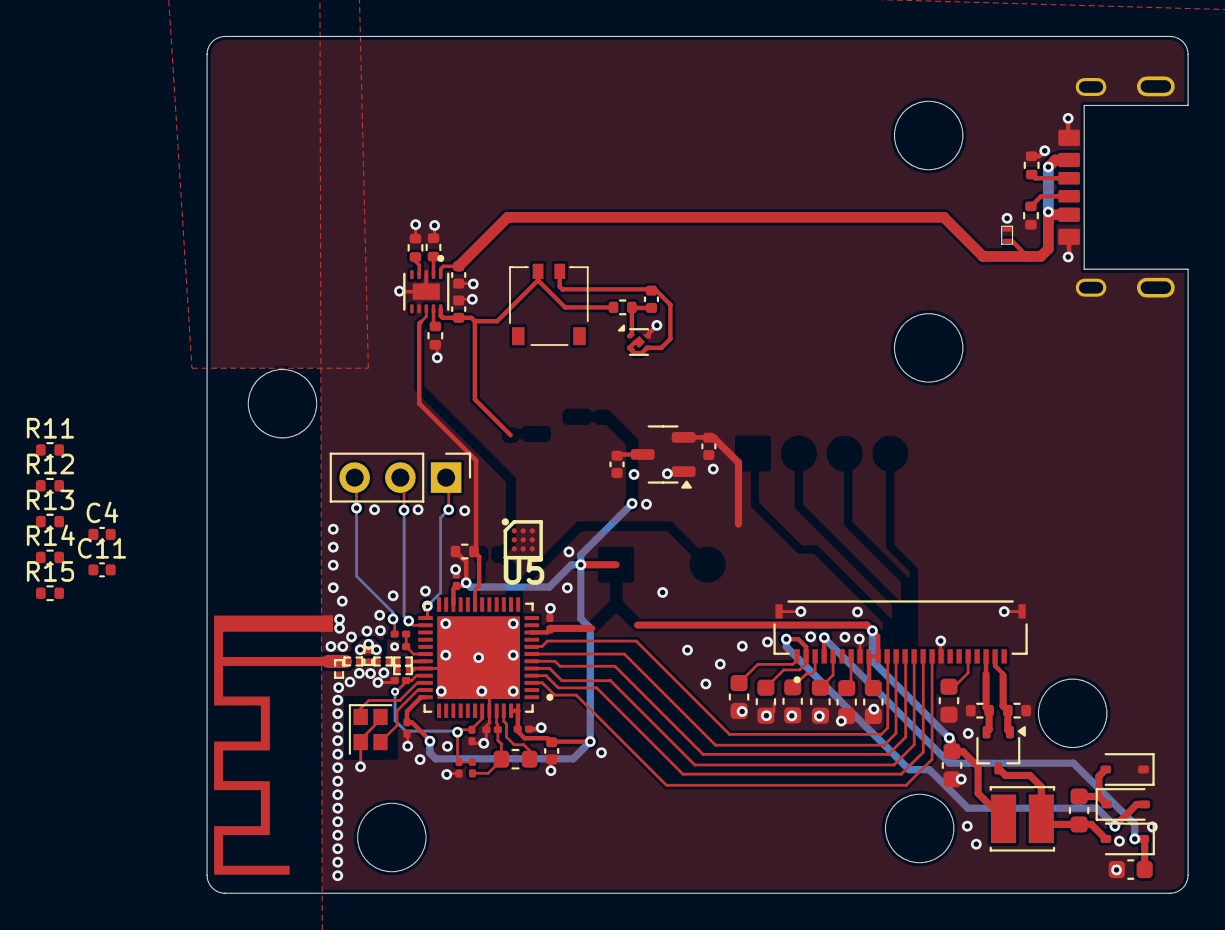
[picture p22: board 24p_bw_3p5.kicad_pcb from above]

Board: 4 copper layers, 54.5 x 47.6 mm, 67 parts (0 on the bottom side), 48 nets.

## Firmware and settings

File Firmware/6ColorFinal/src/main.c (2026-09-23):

#include <errno.h>

#include <zephyr/bluetooth/bluetooth.h>
#include <zephyr/bluetooth/conn.h>
#include <zephyr/device.h>
#include <zephyr/devicetree.h>
#include <zephyr/drivers/spi.h>
#include <zephyr/kernel.h>

#include "battery_status.h"
#include "ble/ble_image_transfer.h"
#include "epd_driver.h"

#define GPIO1_NODE DT_NODELABEL(gpio0)

static const struct device *spi = DEVICE_DT_GET_OR_NULL(DT_NODELABEL(spi30));
static const struct device *gpiob_dev = DEVICE_DT_GET(GPIO1_NODE);
static struct bt_conn *active_conn;

#define ADV_INTERVAL_MIN 2400U /* 1.5 seconds */
#define ADV_INTERVAL_MAX 3200U /* 2.0 seconds */

static const struct bt_data advertising_data[] = {
	BT_DATA_BYTES(BT_DATA_FLAGS, (BT_LE_AD_GENERAL | BT_LE_AD_NO_BREDR)),
	BT_DATA(BT_DATA_NAME_COMPLETE, CONFIG_BT_DEVICE_NAME, sizeof(CONFIG_BT_DEVICE_NAME) - 1),
};

static const struct bt_le_adv_param advertising_param = {
	.id = BT_ID_DEFAULT,
	.options = BT_LE_ADV_OPT_CONN | BT_LE_ADV_OPT_USE_IDENTITY |
		   BT_LE_ADV_OPT_FILTER_SCAN_REQ,
	.interval_min = ADV_INTERVAL_MIN,
	.interval_max = ADV_INTERVAL_MAX,
	.peer = NULL,
};

static int start_advertising(void)
{
	return bt_le_adv_start(&advertising_param, advertising_data,
			       ARRAY_SIZE(advertising_data), NULL, 0);
}

static void advertising_work_handler(struct k_work *work)
{
	ARG_UNUSED(work);

	(void)start_advertising();
}

K_WORK_DEFINE(advertising_work, advertising_work_handler);

static void throughput_work_handler(struct k_work *work)
{
	struct bt_conn *conn;

	ARG_UNUSED(work);

	if (!active_conn) {
		return;
	}

	conn = bt_conn_ref(active_conn);

	(void)bt_conn_le_param_update(conn, BT_LE_CONN_PARAM(6, 12, 0, 400));

#if defined(CONFIG_BT_USER_DATA_LEN_UPDATE)
	(void)bt_conn_le_data_len_update(conn, BT_LE_DATA_LEN_PARAM_MAX);
#endif

#if defined(CONFIG_BT_USER_PHY_UPDATE)
	(void)bt_conn_le_phy_update(conn, BT_CONN_LE_PHY_PARAM_2M);
#endif

	bt_conn_unref(conn);
}

K_WORK_DELAYABLE_DEFINE(throughput_work, throughput_work_handler);

static void connected(struct bt_conn *conn, uint8_t err)
{
	if (err != 0) {
		k_work_submit(&advertising_work);
		return;
	}

	if (active_conn) {
		bt_conn_unref(active_conn);
	}

	active_conn = bt_conn_ref(conn);
	k_work_schedule(&throughput_work, K_MSEC(500));
}

static void disconnected(struct bt_conn *conn, uint8_t reason)
{
	ARG_UNUSED(conn);
	ARG_UNUSED(reason);

	k_work_cancel_delayable(&throughput_work);
	if (active_conn) {
		bt_conn_unref(active_conn);
		active_conn = NULL;
	}

	ble_image_transfer_reset();
}

static void recycled(void)
{
	/* Bluetooth API calls must not be made directly from this callback. */
	k_work_submit(&advertising_work);
}

BT_CONN_CB_DEFINE(connection_callbacks) = {
	.connected = connected,
	.disconnected = disconnected,
	.recycled = recycled,
};

int main(void)
{
	int ret;

	if (!spi || !device_is_ready(spi)) {
		return -ENODEV;
	}

	if (!device_is_ready(gpiob_dev)) {
		return -ENODEV;
	}

	ret = battery_status_init();
	if (ret != 0) {
		/* Battery monitoring is optional at boot so BLE/display still start. */
	}

	ret = epd_configure(spi, gpiob_dev);
	if (ret != 0) {
		return ret;
	}

	ret = epd_bus_suspend();
	if (ret != 0) {
		return ret;
	}

	ret = ble_image_transfer_init();
	if (ret != 0) {
		return ret;
	}

	ret = bt_enable(NULL);
	if (ret != 0) {
		return ret;
	}

	ret = start_advertising();
	if (ret != 0) {
		return ret;
	}

	while (true) {
		k_sleep(K_FOREVER);
	}
}

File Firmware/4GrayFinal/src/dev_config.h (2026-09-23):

#ifndef DEV_CONFIG_H
#define DEV_CONFIG_H

#include <stdbool.h>
#include <stdint.h>
#include <zephyr/device.h>

typedef uint8_t UBYTE;
typedef uint16_t UWORD;
typedef uint32_t UDOUBLE;

enum dev_gpio_pin {
  DEV_PIN_DC = 0,
  DEV_PIN_CS,
  DEV_PIN_RST,
  DEV_PIN_PWR,
};

#define EPD_DC_PIN DEV_PIN_DC
#define EPD_CS_PIN DEV_PIN_CS
#define EPD_RST_PIN DEV_PIN_RST
#define EPD_PWR_PIN DEV_PIN_PWR

#define GPIO_PIN_SET 1
#define GPIO_PIN_RESET 0

int DEV_Module_Init(const struct device *spi_dev, const struct device *gpio_dev);
void DEV_GPIO_Init(void);
void DEV_SPI_Init(void);
int DEV_Digital_Write(uint8_t pin, uint8_t value);
int DEV_Digital_Read(uint8_t pin);
void DEV_Delay_ms(uint32_t xms);
int DEV_SPI_WriteByte(uint8_t data);
int DEV_SPI_Write_nByte(const uint8_t *data, uint32_t len);
void DEV_Module_Exit(void);

#endif

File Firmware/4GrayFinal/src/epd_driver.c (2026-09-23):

#include "dev_config.h"
#include "epd_interface.h"

#include <string.h>
#include <zephyr/devicetree.h>
#include <zephyr/logging/log.h>
#include <zephyr/sys/util.h>
#if defined(CONFIG_PM_DEVICE)
#include <zephyr/pm/device.h>
#endif

LOG_MODULE_REGISTER(epd_driver_4gray);

#define EPD_NODE DT_PATH(zephyr_user)
#define EPD_BUSY_TIMEOUT_MS 45000
#define EPD_CHUNK_BYTES 64U
#define EPD_CS_IDLE 1
#define EPD_CS_ACTIVE 0

enum epd_update_mode {
  EPD_UPDATE_MODE_NONE = 0,
  EPD_UPDATE_MODE_FULL,
  EPD_UPDATE_MODE_FAST,
  EPD_UPDATE_MODE_4GRAY,
};

static const struct device *epd_spi_dev;
static enum epd_update_mode epd_active_mode = EPD_UPDATE_MODE_NONE;
static bool epd_ready;
static bool epd_hibernating;
static const struct gpio_dt_spec epd_busy =
    GPIO_DT_SPEC_GET(EPD_NODE, epd_busy_gpios);

static int epd_cs_idle(void) {
  return DEV_Digital_Write(EPD_CS_PIN, EPD_CS_IDLE);
}

static int epd_cs_active(void) {
  return DEV_Digital_Write(EPD_CS_PIN, EPD_CS_ACTIVE);
}

static int epd_send_command(uint8_t reg) {
  int ret;

  ret = DEV_Digital_Write(EPD_DC_PIN, GPIO_PIN_RESET);
  if (ret != 0) {
    return ret;
  }

  ret = DEV_Digital_Write(EPD_CS_PIN, GPIO_PIN_RESET);
  if (ret != 0) {
    return ret;
  }

  ret = DEV_SPI_WriteByte(reg);
  (void)DEV_Digital_Write(EPD_CS_PIN, GPIO_PIN_SET);
  return ret;
}

static int epd_send_data(uint8_t data) {
  int ret;

  ret = DEV_Digital_Write(EPD_DC_PIN, GPIO_PIN_SET);
  if (ret != 0) {
    return ret;
  }

  ret = DEV_Digital_Write(EPD_CS_PIN, GPIO_PIN_RESET);
  if (ret != 0) {
    return ret;
  }

  ret = DEV_SPI_WriteByte(data);
  (void)DEV_Digital_Write(EPD_CS_PIN, GPIO_PIN_SET);
  return ret;
}

static int epd_send_buffer(const uint8_t *data, size_t len) {
  int ret;

  ret = DEV_Digital_Write(EPD_DC_PIN, GPIO_PIN_SET);
  if (ret != 0) {
    return ret;
  }

  ret = epd_cs_active();
  if (ret != 0) {
    return ret;
  }

  ret = DEV_SPI_Write_nByte(data, (uint32_t)len);
  (void)epd_cs_idle();
  return ret;
}

static int epd_send_data_array(const uint8_t *data, size_t len) {
  int ret;

  for (size_t i = 0U; i < len; ++i) {
    ret = epd_send_data(data[i]);
    if (ret != 0) {
      return ret;
    }
  }

  return 0;
}

static int epd_send_command_data(uint8_t command, const uint8_t *data,
                                 size_t len) {
  int ret;

  ret = epd_send_command(command);
  if (ret != 0) {
    return ret;
  }

  return epd_send_data_array(data, len);
}

static int epd_reset(void) {
  int ret;

  ret = DEV_Digital_Write(EPD_RST_PIN, GPIO_PIN_RESET);
  if (ret != 0) {
    return ret;
  }
  DEV_Delay_ms(10);

  ret = DEV_Digital_Write(EPD_RST_PIN, GPIO_PIN_SET);
  if (ret != 0) {
    return ret;
  }
  DEV_Delay_ms(10);

  epd_hibernating = false;
  return 0;
}

static int epd_wait_idle(void) {
  int timeout_ms = EPD_BUSY_TIMEOUT_MS;
  int busy_level;

  if (!device_is_ready(epd_busy.port)) {
    return -ENODEV;
  }

  while (timeout_ms > 0) {
    busy_level = gpio_pin_get_dt(&epd_busy);
    if (busy_level < 0) {
      return busy_level;
    }

    if (busy_level == 0) {
      return 0;
    }

    DEV_Delay_ms(10);
    timeout_ms -= 10;
  }

  LOG_ERR("EPD busy timeout");
  return -ETIMEDOUT;
}

static int epd_write_repeated(uint8_t value, uint32_t len) {
  uint8_t chunk[EPD_CHUNK_BYTES];
  int ret;

  memset(chunk, value, sizeof(chunk));

  while (len > 0U) {
    uint32_t write_len = MIN(len, (uint32_t)sizeof(chunk));

    ret = epd_send_buffer(chunk, write_len);
    if (ret != 0) {
      return ret;
    }

    len -= write_len;
  }

  return 0;
}

static int epd_set_full_ram_area(uint8_t data_entry_mode) {
  const uint16_t width_end = EPD_PANEL_WIDTH - 1U;
  const uint16_t height_end = EPD_PANEL_HEIGHT - 1U;
  const uint8_t driver_output[] = {
      (uint8_t)(width_end & 0xFFU),
      (uint8_t)(width_end >> 8),
      0x02U,
  };
  const uint8_t entry_mode[] = { data_entry_mode };
  const uint8_t ram_x[] = {
      0x00U,
      0x00U,
      (uint8_t)(height_end & 0xFFU),
      (uint8_t)(height_end >> 8),
  };
  const uint8_t ram_y[] = {
      0x00U,
      0x00U,
      (uint8_t)(width_end & 0xFFU),
      (uint8_t)(width_end >> 8),
  };
  const uint8_t ram_start[] = { 0x00U, 0x00U };
  int ret;

  ret = epd_send_command_data(0x01, driver_output, sizeof(driver_output));
  if (ret != 0) {
    return ret;
  }

  ret = epd_send_command_data(0x11, entry_mode, sizeof(entry_mode));
  if (ret != 0) {
    return ret;
  }

  ret = epd_send_command_data(0x44, ram_x, sizeof(ram_x));
  if (ret != 0) {
    return ret;
  }

  ret = epd_send_command_data(0x45, ram_y, sizeof(ram_y));
  if (ret != 0) {
    return ret;
  }

  ret = epd_send_command_data(0x4E, ram_start, sizeof(ram_start));
  if (ret != 0) {
    return ret;
  }

  return epd_send_command_data(0x4F, ram_start, sizeof(ram_start));
}

static int epd_panel_init(enum epd_update_mode mode) {
  const uint8_t booster_soft_start[] = { 0xAEU, 0xC7U, 0xC3U, 0xC0U, 0x80U };
  const uint8_t border_waveform[] = { 0x01U };
  const uint8_t temp_sensor[] = { 0x80U };
  const uint8_t mode_4gray[] = { 0x5AU };
  const uint8_t mode_fast[] = { 0x6AU };
  int ret;

  ret = epd_reset();
  if (ret != 0) {
    return ret;
  }

  ret = epd_wait_idle();
  if (ret != 0) {
    return ret;
  }

  ret = epd_send_command(0x12);
  if (ret != 0) {
    return ret;
  }

  ret = epd_wait_idle();
  if (ret != 0) {
    return ret;
  }

  if (mode == EPD_UPDATE_MODE_FULL) {
    ret = epd_send_command_data(0x18, temp_sensor, sizeof(temp_sensor));
    if (ret != 0) {
      return ret;
    }
  }

  ret = epd_send_command_data(0x0C, booster_soft_start,
                              sizeof(booster_soft_start));
  if (ret != 0) {
    return ret;
  }

  if (mode == EPD_UPDATE_MODE_FULL) {
    ret = epd_send_command_data(0x3C, border_waveform,
                                sizeof(border_waveform));
    if (ret != 0) {
      return ret;
    }
  }

  ret = epd_set_full_ram_area(0x03U);
  if (ret != 0) {
    return ret;
  }

  ret = epd_wait_idle();
  if (ret != 0) {
    return ret;
  }

  if (mode != EPD_UPDATE_MODE_FULL) {
    ret = epd_send_command_data(0x3C, border_waveform,
                                sizeof(border_waveform));
    if (ret != 0) {
      return ret;
    }

    ret = epd_send_command_data(0x18, temp_sensor, sizeof(temp_sensor));
    if (ret != 0) {
      return ret;
    }

    if (mode == EPD_UPDATE_MODE_4GRAY) {
      ret = epd_send_command_data(0x1A, mode_4gray, sizeof(mode_4gray));
    } else {
      ret = epd_send_command_data(0x1A, mode_fast, sizeof(mode_fast));
    }
    if (ret != 0) {
      return ret;
    }
  }

  epd_active_mode = mode;
  epd_ready = true;
  epd_hibernating = false;
  return 0;
}

static int epd_prepare_update(enum epd_update_mode mode) {
  if (!epd_ready || epd_hibernating || epd_active_mode != mode) {
    return epd_panel_init(mode);
  }

  return 0;
}
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

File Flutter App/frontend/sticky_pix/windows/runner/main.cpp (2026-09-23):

#include <flutter/dart_project.h>
#include <flutter/flutter_view_controller.h>
#include <windows.h>

#include "flutter_window.h"
#include "utils.h"

int APIENTRY wWinMain(_In_ HINSTANCE instance, _In_opt_ HINSTANCE prev,
                      _In_ wchar_t *command_line, _In_ int show_command) {
  // Attach to console when present (e.g., 'flutter run') or create a
  // new console when running with a debugger.
  if (!::AttachConsole(ATTACH_PARENT_PROCESS) && ::IsDebuggerPresent()) {
    CreateAndAttachConsole();
  }

  // Initialize COM, so that it is available for use in the library and/or
  // plugins.
  ::CoInitializeEx(nullptr, COINIT_APARTMENTTHREADED);

  flutter::DartProject project(L"data");

  std::vector<std::string> command_line_arguments =
      GetCommandLineArguments();

  project.set_dart_entrypoint_arguments(std::move(command_line_arguments));

  FlutterWindow window(project);
  Win32Window::Point origin(10, 10);
  Win32Window::Size size(1280, 720);
  if (!window.Create(L"sticky_pix", origin, size)) {
    return EXIT_FAILURE;
  }
  window.SetQuitOnClose(true);

  ::MSG msg;
  while (::GetMessage(&msg, nullptr, 0, 0)) {
    ::TranslateMessage(&msg);
    ::DispatchMessage(&msg);
  }

  ::CoUninitialize();
  return EXIT_SUCCESS;
}
